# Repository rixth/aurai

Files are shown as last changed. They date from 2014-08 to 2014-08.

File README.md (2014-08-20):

# aurai

Helping traditional air conditioners join the Internet of Things -  Aurai allows any AC that has a remote control to be controlled via a modern web interface.

This is an entry in to the Hackaday Prize. Details build logs are available on the [project page](https://hackaday.io/project/2288).

## The hardware

Aurai comprises of two hardware components. The first is the base  station (or "hub") which connects to a computer over a USB-UART. The second component, referred to as the "spoke", contains the infrared transmitter to talk to the AC and environmental monitoring sensors. The two units communicate with each other over a wireless connection.

## The software

I have found that many home automation software packages have atrocious interfaces. I tried to ensure that Aurai does not.

screenshot of the interface

## The firmware

The hub & spoke communicate using a series of simple commands over the radio link. The hub should be able to ask the spoke for current environmental data, or to turn on the AC, set target temperature, etc. The spoke firmware contains a state machine to keep track of the air conditioner's state, as some commands are not always valid (ie. you can't set the target temperature when the AC mode is set to "fan only").

## License

Aurai's hardware, firmware & software are licensed under the GPL. The project uses avr-libc extensively, which is under a modified BSD license.

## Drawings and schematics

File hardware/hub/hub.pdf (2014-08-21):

A

A

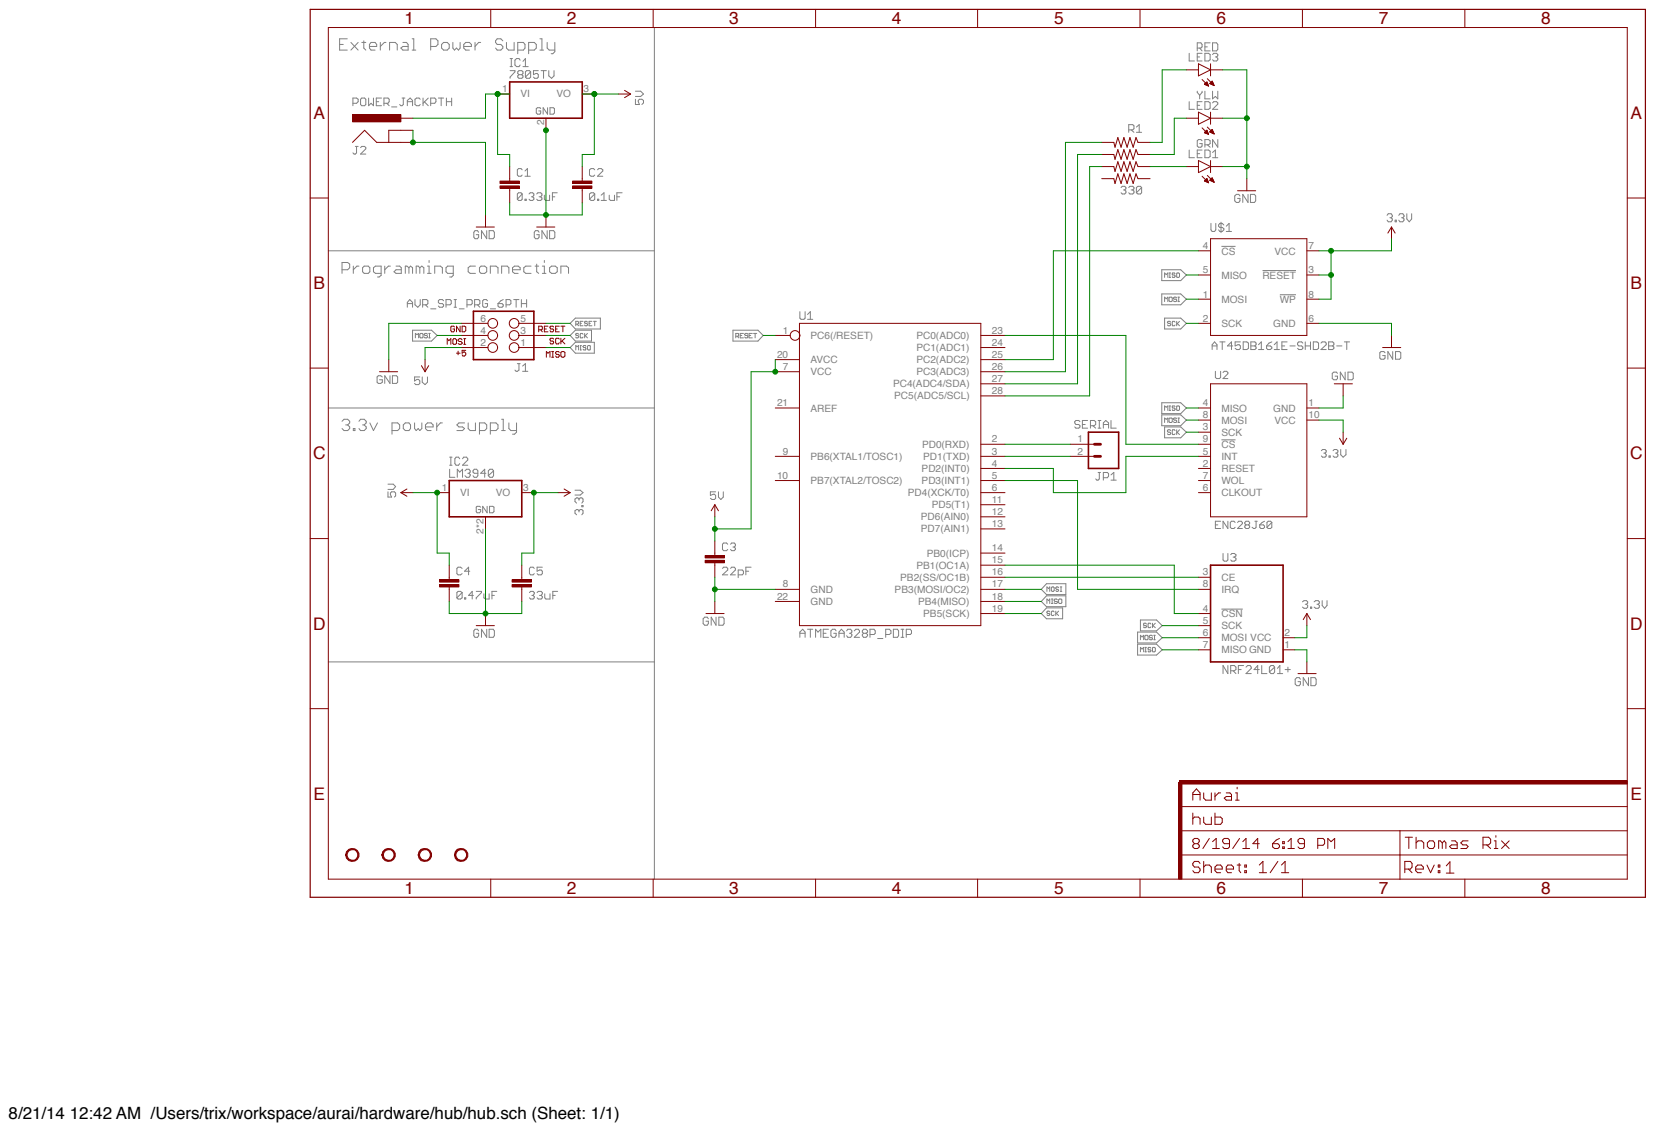
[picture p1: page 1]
PB5(SCK); PB7(XTAL2/TOSC2) 10; PB6(XTAL1/TOSC1) 9; GND 8 GND 22; VCC 7; AREF 21; AVCC 20; PB4(MISO); 18 PB3(MOSI/OC2); 15 PB0(ICP); PD7(AIN1); 13 PD6(AIN0); 11 PD4(XCK/T0); 6 PD3(INT1); 5 PD2(INT0); 4 PD1(TXD); 3 PD0(RXD); PC5(ADC5/SCL); 28 PC4(ADC4/SDA); 27 PC3(ADC3); 26 PC2(ADC2); 25 PC1(ADC1); 24 PC0(ADC0); 23 PC6(/RESET) 1; CSN 4 SCK 5 MOSI 6; MISO 7; VCC; GND; CE 3 IRQ 8; MISO 5; MOSI 1; SCK 2; RESET; 10 MISO 4; MOSI 8 SCK 3 CS 9 INT 5 RESET 2 WOL 7; CLKOUT 6 VI 1

8/21/14 12:42 AM /Users/trix/workspace/aurai/hardware/hub/hub.sch (Sheet: 1/1)

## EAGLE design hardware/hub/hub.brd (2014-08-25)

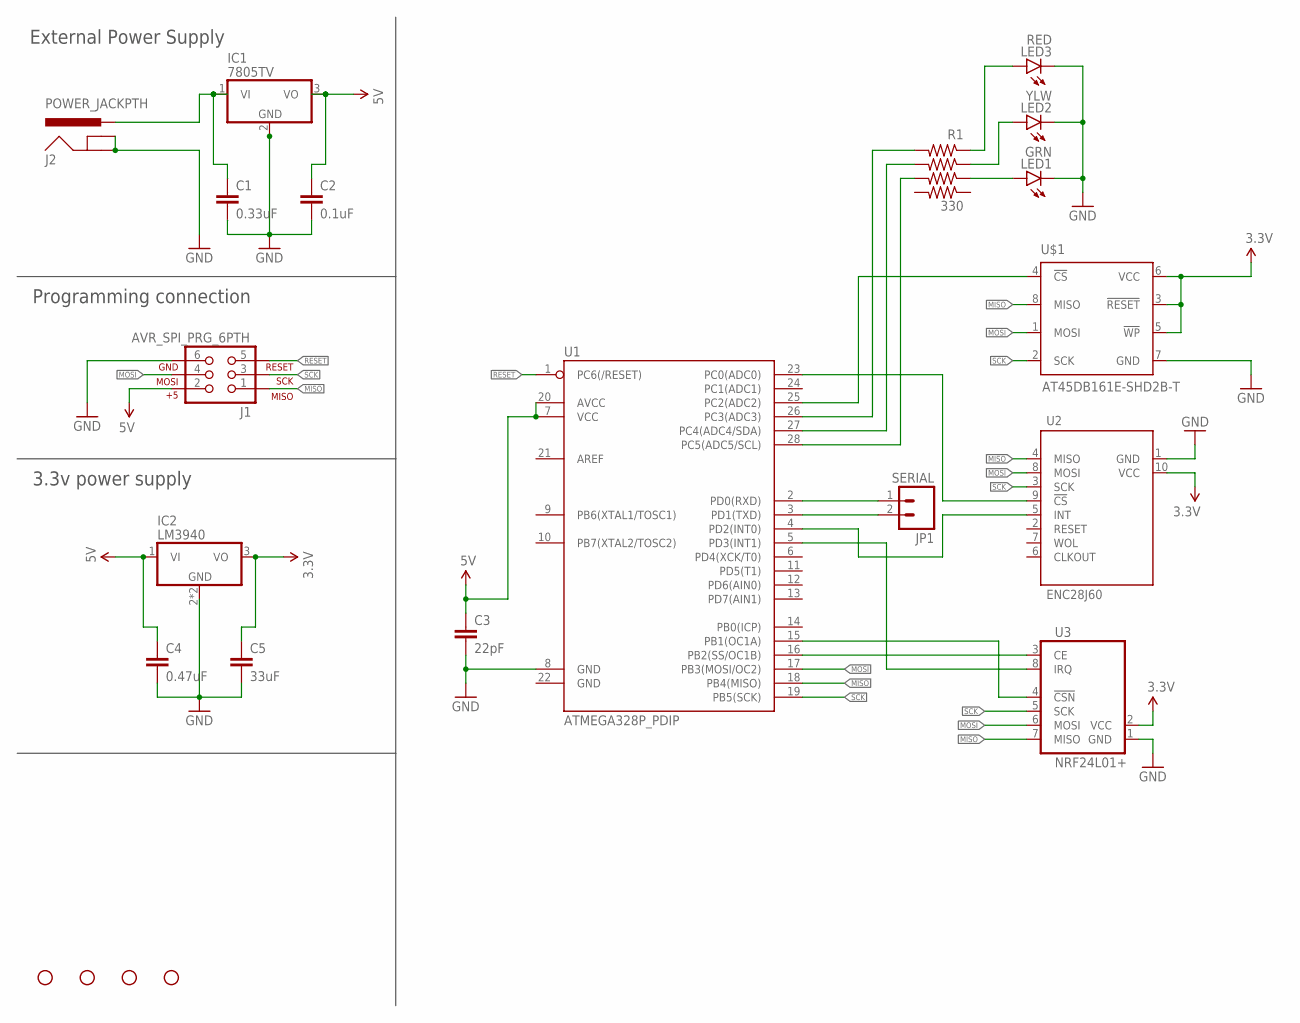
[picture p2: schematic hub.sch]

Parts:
C1: 0.33uF; 0805
C2: 0.1uF; 0805
C3: 22pF; 0805
C4: 0.47uF; 0805
C5: 33uF; 0805
IC1: 7805TV; TO220V
IC2: LM3940; SOT223
J1: AVR_SPI_PRG_6PTH; 2X3
J2: POWER_JACKPTH; POWER_JACK_PTH
JP1: SERIAL; 1X02
LED1: GRN; LED-1206
LED2: YLW; LED-1206
LED3: RED; LED-1206
R1: 330; CRA06S08
STANDOFF1, STANDOFF2, STANDOFF3, STANDOFF4: STAND-OFF
U1: ATMEGA328P_PDIP; DIL28-3
U2: ENC28J60; ENC28J60_HEADER
U3: NRF24L01+; NRF24L01_HEADER
U$1: AT45DB161E-SHD2B-T; SO08-EIAJ

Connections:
3.3V: C5.1, IC2.3 (VO), U2.10 (VCC), U3.2 (VCC), U$1.3 (!RESET), U$1.5 (!WP), U$1.6 (VCC)
5V: C2.1, C3.1, C4.1, IC1.3 (VO), IC2.1 (VI), J1.2, U1.7 (VCC), U1.20 (AVCC)
GND: C1.2, C2.2, C3.2, C4.2, C5.2, IC1.2 (GND), IC2.2 (GND), IC2.4 (GND), J1.6, J2.GND, J2.GNDBREAK, LED1.C, LED2.C, LED3.C, U1.8 (GND), U2.1 (GND), U3.1 (GND), U$1.7 (GND)
MISO: J1.1, U1.18 (PB4(MISO)), U2.4 (MISO), U3.7 (MISO), U$1.8 (MISO)
MOSI: J1.4, U1.17 (PB3(MOSI/OC2)), U2.8 (MOSI), U3.6 (MOSI), U$1.1 (MOSI)
unnamed: LED1.A, R1.3 (R3A)
unnamed: JP1.1, U1.2 (PD0(RXD))
unnamed: R1.7 (R2B), U1.27 (PC4(ADC4/SDA))
unnamed: JP1.2, U1.3 (PD1(TXD))
unnamed: R1.8 (R1B), U1.26 (PC3(ADC3))
unnamed: LED3.A, R1.1 (R1A)
unnamed: U1.15 (PB1(OC1A)), U3.4 (!CSN)
unnamed: LED2.A, R1.2 (R2A)
unnamed: U1.16 (PB2(SS/OC1B)), U3.3 (CE)
unnamed: U1.5 (PD3(INT1)), U3.8 (IRQ)
unnamed: U1.25 (PC2(ADC2)), U$1.4 (!CS)
unnamed: R1.6 (R3B), U1.28 (PC5(ADC5/SCL))
unnamed: U1.23 (PC0(ADC0)), U2.9 (!CS)
unnamed: C1.1, IC1.1 (VI), J2.PWR
unnamed: U1.4 (PD2(INT0)), U2.5 (INT)
RESET: J1.5, U1.1 (PC6(/RESET))
SCK: J1.3, U1.19 (PB5(SCK)), U2.3 (SCK), U3.5 (SCK), U$1.2 (SCK)

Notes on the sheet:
External Power Supply
Programming connection
3.3v power supply

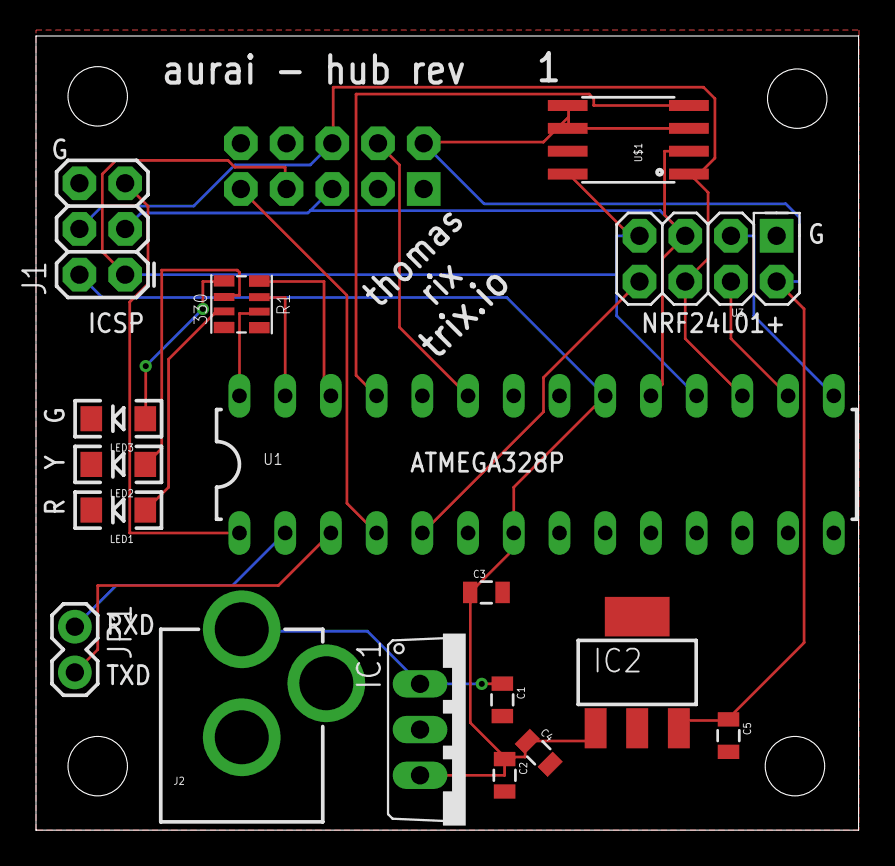
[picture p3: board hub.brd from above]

Board: 2 copper layers, 45.7 x 44.1 mm, 22 parts (1 on the bottom side), 22 nets.

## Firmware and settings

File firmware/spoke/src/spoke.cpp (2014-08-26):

#include <util/delay.h>

#include <pins.h>
#include <SPI.h>
#include <DiagLEDS.h>
#include <Serial.h>
#include <DHT11.h>
#include <IRSend.h>
#include <NRF24L01.h>
#include <EEPROM.h>
#include <SpokeCommands.h>
#include <AirConditioner.h>

#include <spoke.h>

AirConditioner ac;

int main() {
  Serial.begin();
  SPI.begin();
  DiagLEDS_init();
  NRF24_init();

  while (1) {
    DiagLEDS_set(LED_ALL);
    _delay_ms(100);
    DiagLEDS_set(0);

    Serial.println("Aurai SPOKE.");
    Serial.println(" [B] Boot");
    Serial.println(" [?] Enter test mode");
    Serial.print("Will auto-choose [B] in 3 seconds... ");

    uint8_t cmd = 'b';

    uint16_t i = 0;
    while (++i < 3000) {
      if (Serial.available()) {
        cmd = Serial.read();
        break;
      }
      _delay_ms(1);
    };

    if (!cmd) {
      Serial.println(" timeout!");
    } else {
      Serial.println("");
    }

    if (cmd == 'b') {
      Serial.println("Booting!");
      boot();
    } else {
      // mainTest(cmd);
    }
  }

  return 0;
}

void boot() {
  initializeRadio();
  ac.restoreStateFromMemory();
  DiagLEDS_set(LED_GRN);
  while (!Serial.available()) {
    if (NRF24_dataAvailable()) {
      processIncomingData();
      ac.saveStateToMemory();
    }
    // TODO sleep here
  }
  Serial.read();
}

void initializeRadio() {
  NRF24_flush();
  NRF24_configure();
  NRF24_setRxAddr((uint8_t *)"spoke", 5);
  NRF24_setTxAddr((uint8_t *)"hub__", 5);
  NRF24_rxMode();
}

void processIncomingData() {
  uint8_t data[2];
  uint8_t len = NRF24_fetch(data, 2);

  Serial.print("Received: ");
  uint8_t i;
  for (i = 0; i < len; i++) {
    Serial.puth(data[i]);
    if (i != (len - 1)) {
      Serial.print(" ");
    }
  }
  Serial.print("\r\n");

  // The first 5 bits are the command so shift the rest off
  uint8_t cmd = data[0] >> 3 << 3;

  bool success = false;
  bool sendReply = true;

  if (cmd == SPOKE_CMD_POWER) {
    if (data[0] == SPOKE_CMD_POWER_PRM_TOGGLE) {
      ac.togglePower();
      success = true;
    } else if (data[0] == SPOKE_CMD_POWER_PRM_OFF) {
      success = ac.powerOff();
    } else if (data[0] == SPOKE_CMD_POWER_PRM_ON) {
      success = ac.powerOn();
    }
  } else if (cmd == SPOKE_CMD_TEMPERATURE) {
    if (data[0] == SPOKE_CMD_TEMPERATURE_PRM_UP) {
      success = ac.targetTempUp();
    } else if (data[0] == SPOKE_CMD_TEMPERATURE_PRM_DOWN) {
      success = ac.targetTempDown();
    }
  } else if (cmd == SPOKE_CMD_TEMPERATURE_EXACT) {
    if (len == 2) {
      success = ac.setTargetTemp(data[1]);
    }
  } else if (cmd == SPOKE_CMD_FAN_SPEED) {
    if (data[0] == SPOKE_CMD_FAN_SPEED_PRM_NEXT) {
      success = ac.nextFanSpeed();
    } else if (data[0] == SPOKE_CMD_FAN_SPEED_PRM_LOW) {
      success = ac.setFanSpeed(AC_FAN_SPD_LOW);
    } else if (data[0] == SPOKE_CMD_FAN_SPEED_PRM_MED) {
      success = ac.setFanSpeed(AC_FAN_SPD_MED);
    } else if (data[0] == SPOKE_CMD_FAN_SPEED_PRM_HIGH) {
      success = ac.setFanSpeed(AC_FAN_SPD_HIGH);
    }
  } else if (cmd == SPOKE_CMD_MODE) {
    if (data[0] == SPOKE_CMD_MODE_PRM_NEXT) {
      success = ac.nextMode();
    } else if (data[0] == SPOKE_CMD_MODE_PRM_COOL) {
      success = ac.setMode(AC_MODE_COOL);
    } else if (data[0] == SPOKE_CMD_MODE_PRM_ENERGY_SAVER) {
      success = ac.setMode(AC_MODE_ENERGY_SAVER);
    } else if (data[0] == SPOKE_CMD_MODE_PRM_DRY) {
      success = ac.setMode(AC_MODE_DRY);
    } else if (data[0] == SPOKE_CMD_MODE_PRM_FAN) {
      success = ac.setMode(AC_MODE_FAN);
    }
  } else if (cmd == SPOKE_CMD_RESET) {
    ac.reset();
    success = true;
  } else if (cmd == SPOKE_CMD_STATUS) {
    uint16_t acStatus = ac.status();
    uint8_t reply[SPOKE_STATUS_LEN] = { \
      SPOKE_RESP_STATUS,
      (uint8_t) (acStatus >> 8),
      (uint8_t) (acStatus & 0xFF)
    };

    Serial.print("Sending status: ");
    if (NRF24_send(reply, SPOKE_STATUS_LEN)) {
      Serial.println("ok");
    } else {
      Serial.println("failed");
    }
    success = true;
  } else if (cmd == SPOKE_CMD_ENV) {
    DHT11_readSensor();
    uint8_t reply[SPOKE_ENV_LEN] = { \
      SPOKE_RESP_ENV,
      DHT11_humidity(),
      (uint8_t) DHT11_temperature(),
    };

    Serial.print("Sending environment: ");
    if (NRF24_send(reply, SPOKE_ENV_LEN)) {
      Serial.println("ok");
    } else {
      Serial.println("failed");
    }
    success = true;
  }

  if (sendReply) {
    uint16_t acStatus = ac.status();
    uint8_t reply[SPOKE_STATUS_LEN] = { \
      SPOKE_RESP_OK,
      (uint8_t) (acStatus >> 8),
      (uint8_t) (acStatus & 0xFF)
    };

    if (success) {
      Serial.print("Sending success reply: ");
    } else {
      Serial.print("Sending failure reply: ");
      reply[0] = SPOKE_RESP_FAIL;
    }

    if (NRF24_send(reply, SPOKE_STATUS_LEN)) {
      Serial.println("ok");
    } else {
      Serial.println("failed");
    }
  }

  DiagLEDS_set(success ? LED_GRN : LED_RED);
  if (!sendReply) {
    Serial.println(success ? "Command succeeded." : "Command failed.");
  }
}

void mainTest(uint8_t input) {
  NRF24_test(input);
  IRSend_test();
  DHT11_test();
  EEPROM.test(input);
  DiagLEDS_test(input);
}

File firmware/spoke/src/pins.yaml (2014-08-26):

---
red_led: 26
ylw_led: 27
grn_led: 28
dht11: 25
irled: 5
nrf24_ce: 15
nrf24_csn: 16

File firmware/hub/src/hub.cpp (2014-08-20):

#include <avr/interrupt.h>
#include <util/delay.h>

#include <pins.h>
#include <SPI.h>
#include <DiagLEDS.h>
#include <Serial.h>
#include <Flash.h>
#include <EEPROM.h>
#include <NRF24L01.h>
#include <SpokeCommands.h>
#include "CommandLine.h"
#include "SerialInterface.h"
#include "EnvironmentalLogger.h"

#include <hub.h>

volatile uint8_t cycleCount = 0;
volatile uint32_t secondsSinceBoot = 0;

ISR(TIMER0_COMPA_vect) {
  cycleCount++;
  if (cycleCount == 36) {
    secondsSinceBoot++;
    cycleCount = 0;
  }
}

int main() {
  Flash_init();
  Serial.begin();
  SPI.begin();
  DiagLEDS_init();
  NRF24_init();
  sei();

  while (1) {
    Serial.println("Aurai HUB.");
    Serial.println(" [X] Command line");
    Serial.println(" [S] Binary serial interface");
    Serial.println(" [B] Boot");
    Serial.println(" [?] Enter test mode");
    Serial.print("Will auto-choose [S] in 3 seconds... ");

    uint8_t cmd = 's';

    uint16_t i = 0;
    while (++i < 3000) {
      if (Serial.available()) {
        cmd = Serial.read();
        break;
      }
      _delay_ms(1);
    };

    if (!cmd) {
      Serial.println(" timeout!");
    } else {
      Serial.println("Booting!");
    }

    if (cmd == 'x') {
      commonStart();
      DiagLEDS_set(LED_YLW);
      CommandLine_start();
    } else if (cmd == 's' || cmd == 'b') {
      Serial.println("Starting Serial interface!");
      commonStart();
      DiagLEDS_set(LED_GRN);
      boot();
    } else {
      // mainTest(cmd);
    }
  }

  return 0;
}

void boot() {
  while(1) {
    EnvironmentalLogging_logIfNeeded(secondsSinceBoot);
    SerialInterface_start();
  }
}

void timerInit() {
  OCR0A  = 217; // will trigger ~36hz at 8mhz
  TIMSK0 = _BV(OCIE0A);
  TCCR0A = _BV(WGM01);
  TCCR0B = _BV(CS02) | _BV(CS00);
}

void commonStart() {
  EnvironmentalLogging_start();
  timerInit();
  initializeRadio();
}

void initializeRadio() {
  NRF24_flush();
  NRF24_configure();
  NRF24_setTxAddr((uint8_t *)"spoke", 5);
  NRF24_setRxAddr((uint8_t *)"hub__", 5);
}

void mainTest(uint8_t input) {
  NRF24_test(input);
  Flash_test(input);
  DiagLEDS_test(input);
  EEPROM.test(input);
}

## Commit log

2014-08-06 Empty schematics for the hub and spoke
    [hub.sch, spoke.sch]
2014-08-07 Put some bits on a schematic
    [spoke.sch]
2014-08-08 Add SOIC-8 EIAJ footprint, and AT25M01 package for it
2014-08-08 Update spoke schematic
    [spoke.sch]
2014-08-08 Schematic update for spoke. Added DHT-11 and LEDS
    [spoke.sch]
2014-08-08 Fix bad wiring in PSU
    [spoke.sch]
2014-08-08 Beginnings of a board
    [spoke.brd]
2014-08-09 MOAR SMDs and 3.3v supply fixes
    [spoke.brd, spoke.sch]
2014-08-09 Test code for SerialIO_hasData manipulating LEDs
2014-08-10 DHT-11 sensor reading
2014-08-10 DHT11 library no longer needs micros function
    [DHT11.cpp, spoke.cpp]
2014-08-10 Move EEPROM_CS and make sure we use the defined pin
2014-08-10 Update schematic from todos
    [spoke.brd, spoke.sch]
2014-08-11 Adjust schematic. Begin routing.
    [spoke.brd, spoke.sch]
2014-08-11 Finish routing spoke!
    [spoke.brd, spoke.sch]
2014-08-11 Remove AT25M01 EEPROM from Spoke
    [spoke.sch]
2014-08-11 Add real 3.3v LDO regulator
    [spoke.sch]
2014-08-11 Add resistor array and LM3904 parts
2014-08-12 Update spoke board
    [spoke.brd, spoke.sch]
2014-08-12 Bump spoke revision to 2
    [spoke.brd, spoke.sch]
2014-08-13 Fix up EEPROM includes
    [EEPROM.cpp]
2014-08-15 Move from LM3490 to LM3940 regulator
    [spoke.brd, spoke.sch]
2014-08-16 Use rn's
    [hub.brd]
2014-08-16 This PWM code messes /w OC2A too (MISO).
    Not sure why this is, but so I'm turning the timer on and off completly.
    In the future, I'll move the LED to a different timer.
2014-08-17 Move to object-based SPI
2014-08-17 Move SPI eeprom code in to the hub source
2014-08-17 Working wireless link to toggle the AC!
2014-08-18 User interface mock
    [hub.sch]
2014-08-19 Send command success/fail back
    [CommandLine.cpp, spoke.cpp]
2014-08-19 Pretty printing of status
2014-08-19 Save/restore AC state. Green LED on first boot.
2014-08-19 Take advantage of the diagnostic LEDs
2014-08-19 Use LEDs to indicate boot mode
2014-08-19 Noob bitwise logic error
    [spoke.cpp]
2014-08-19 Properly validate fan speed requests
2014-08-20 Put commands in a queue to be processed to avoid messing up the serial communication
    [ac.js]
2014-08-20 Cast arguments to the correct type
    [ac.js]
2014-08-20 SerialInterface doesn't lock anymore
    [SerialInterface.cpp, hub.cpp]
2014-08-20 Set up a timer that increases a seconds counter
2014-08-20 Only YOU can prevent forest crashes
    [ac.js]
2014-08-21 Schematic PDFs
2014-08-25 Fix flash pinout. Finish hub brd
    [hub.brd, hub.sch]
2014-08-26 Flash diag LEDs at first start

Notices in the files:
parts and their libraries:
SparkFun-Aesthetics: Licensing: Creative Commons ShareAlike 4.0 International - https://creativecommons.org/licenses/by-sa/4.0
